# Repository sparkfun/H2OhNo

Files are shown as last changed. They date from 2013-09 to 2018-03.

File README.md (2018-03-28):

**Note:Retired Product**
This product has been retired from our catalog and is no longer for sale. This page is made available for those looking for datasheets and the simply curious.

H2OhNo
======

[H2OhNo 
*H20hNo (DEV-12069)*](https://www.sparkfun.com/products/12069)

H2OhNo! is a small ATtiny development board that detects the presence of water and sets off an alarm.

Repository Contents
-------------------

* **/Firmware** - Example firmware for running the sensor
* **/Hardware** - All Eagle design files (.brd, .sch)

Documentation
-------------------
* **[Hookup Guide](https://learn.sparkfun.com/tutorials/h2ohno)** - Basic hookup guide for the H2OhNo

License Information
-------------------
The hardware is released under [Creative Commons Share-alike 3.0](http://creativecommons.org/licenses/by-sa/3.0/).  
All other code is open source so please feel free to do anything you want with it; you buy me a beer if you use this and we meet someday ([Beerware license](http://en.wikipedia.org/wiki/Beerware)).

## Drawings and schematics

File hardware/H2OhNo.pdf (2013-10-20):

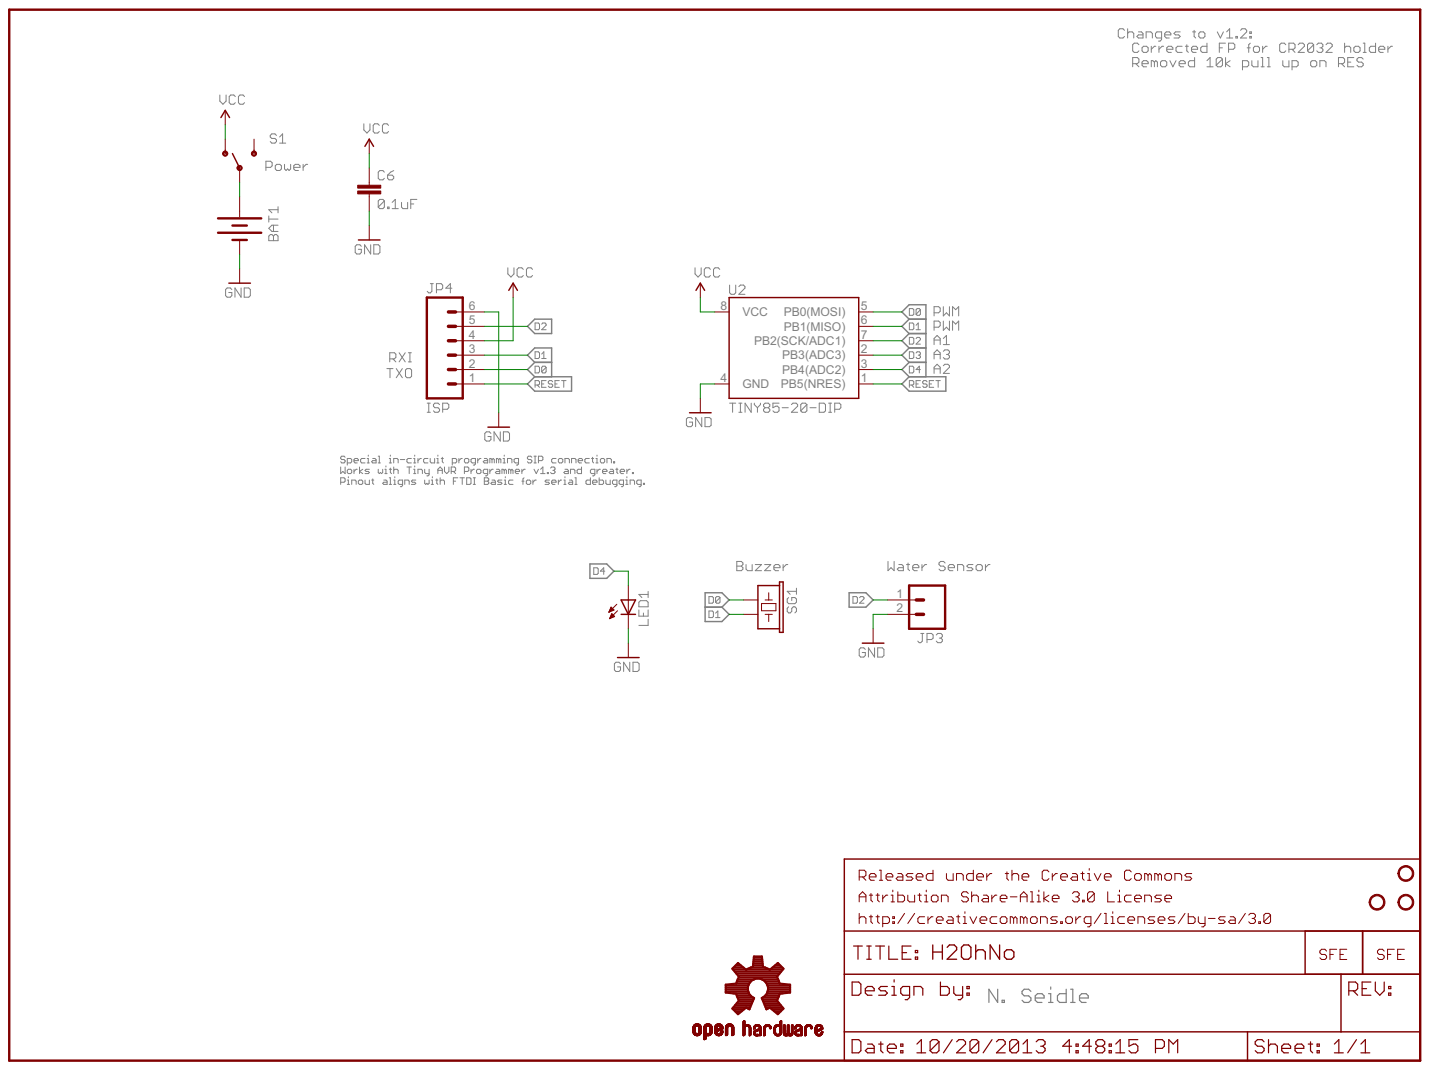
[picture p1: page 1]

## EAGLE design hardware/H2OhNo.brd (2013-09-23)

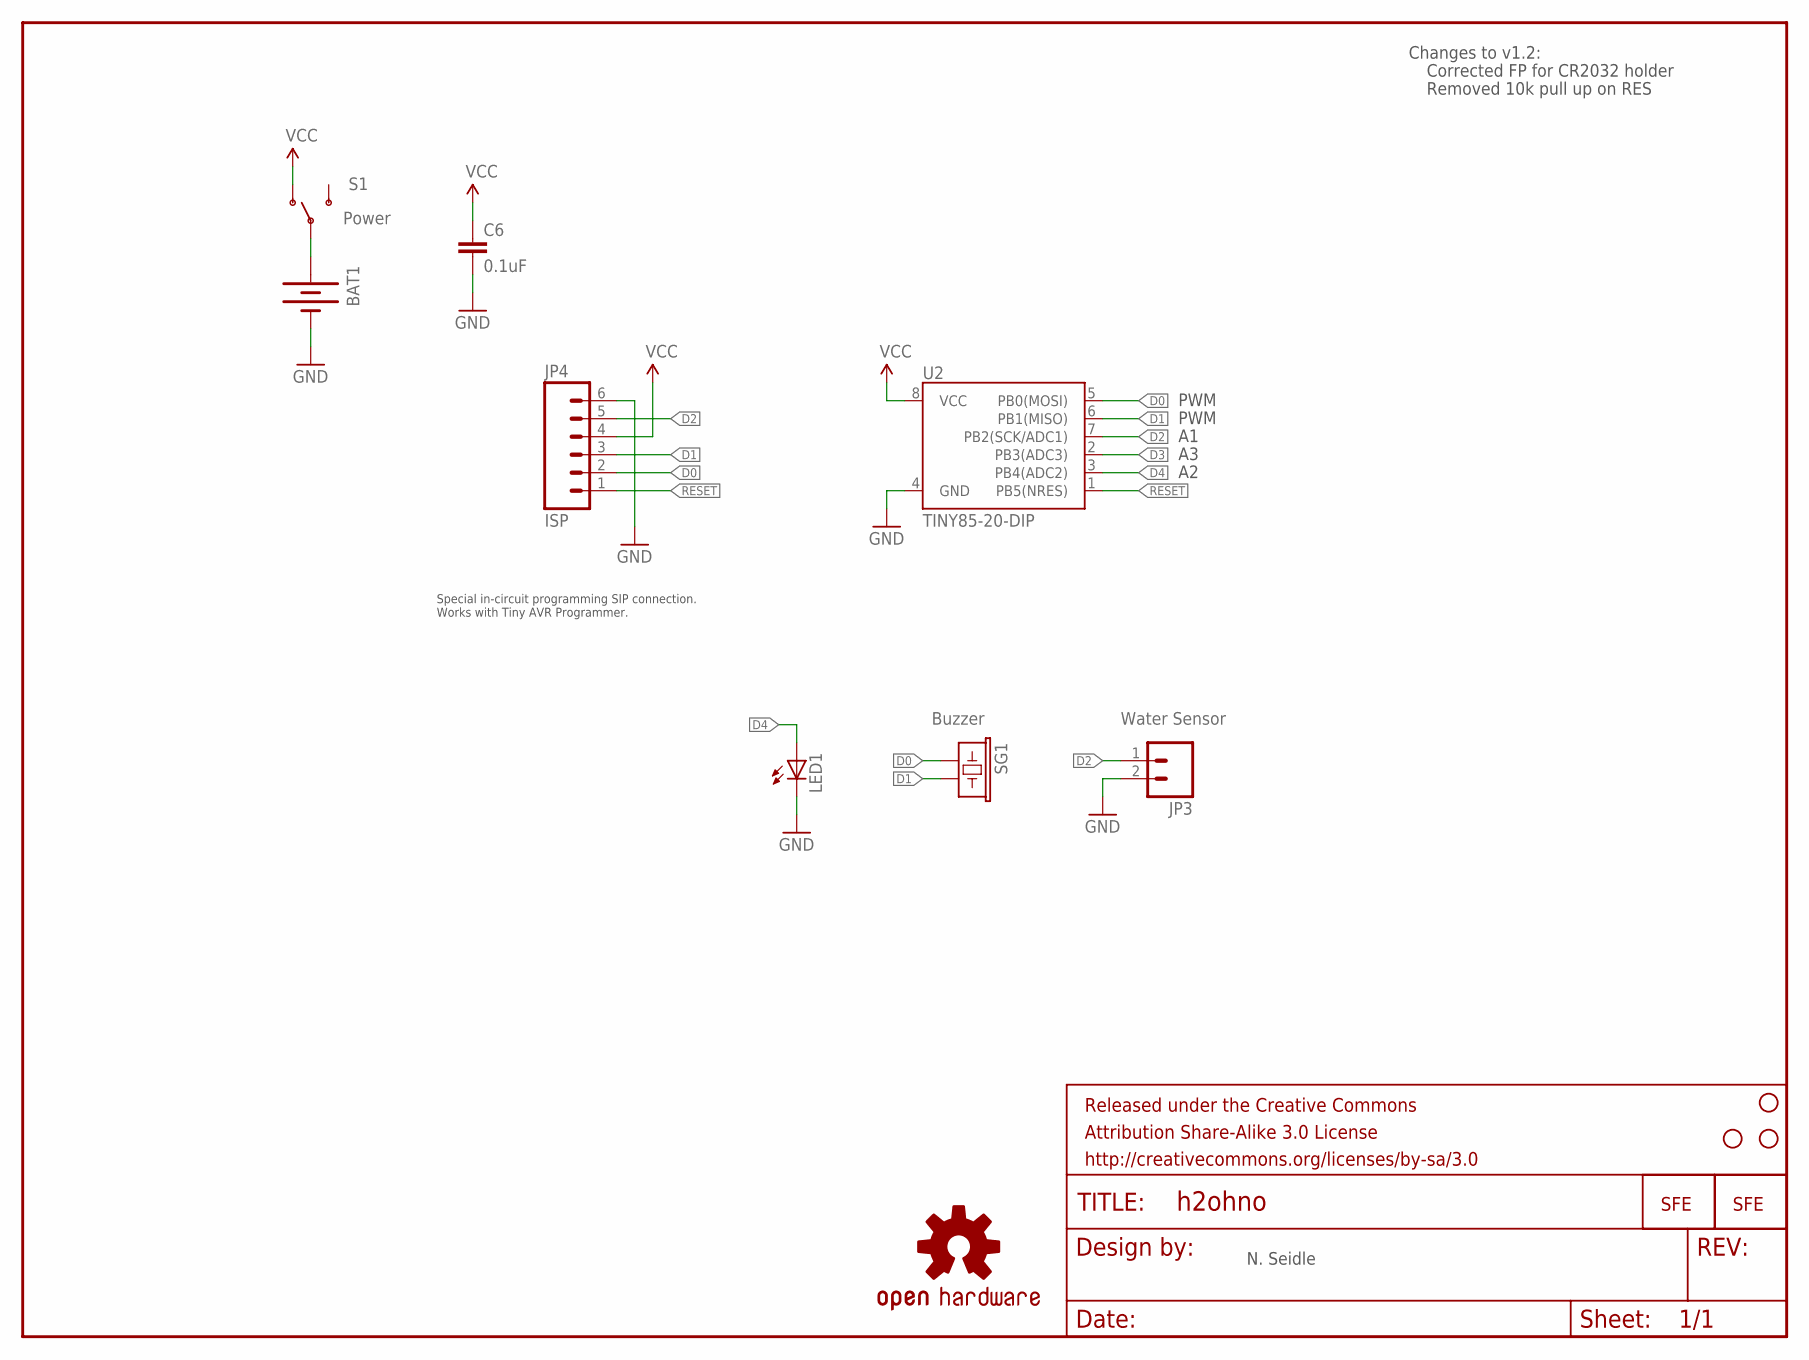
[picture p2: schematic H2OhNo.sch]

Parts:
BAT1: BATTERY20PTH; BATTCOM_20MM_PTH
C6: 0.1uF; CAP-PTH-SMALL2
FRAME2: FRAME-LETTER; CREATIVE_COMMONS
JP3: Water Sensor; 1X02
JP4: ISP; 1X06
LED1: LED5MM
S1: Power; SWITCH-SPDT
SG1: Buzzer; BUZZER-12MM
STANDOFF1, STANDOFF3, STANDOFF4: STAND-OFF
U2: TINY85-20-DIP; DIP08
U$1: LOGO-SFESK; SFE-LOGO-FLAME
U$4: OSHW-LOGOS; OSHW-LOGO-S
U$5: LOGO-SFENW2; SFE-NEW-WEB

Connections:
D0: JP4.2, SG1.+ (1), U2.5 (PB0(MOSI))
D1: JP4.3, SG1.- (2), U2.6 (PB1(MISO))
D2: JP3.1, JP4.5, U2.7 (PB2(SCK/ADC1))
D3: U2.2 (PB3(ADC3))
D4: LED1.A, U2.3 (PB4(ADC2))
GND: BAT1.2 (-), C6.2, JP3.2, JP4.6, LED1.K (C), U2.4 (GND)
unnamed: BAT1.1 (+), S1.2
RESET: JP4.1, U2.1 (PB5(NRES))
VCC: C6.1, JP4.4, S1.1 (O), U2.8 (VCC)

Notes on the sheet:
N. Seidle
Changes to v1.2:
PWM
Corrected FP for CR2032 holder
Removed 10k pull up on RES
Special in-circuit programming SIP connection. Works with Tiny AVR Programmer.

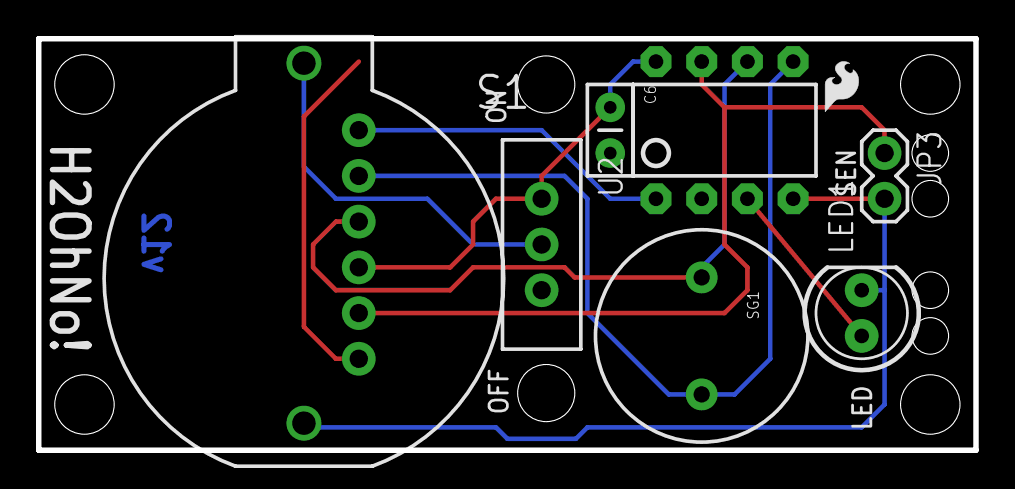
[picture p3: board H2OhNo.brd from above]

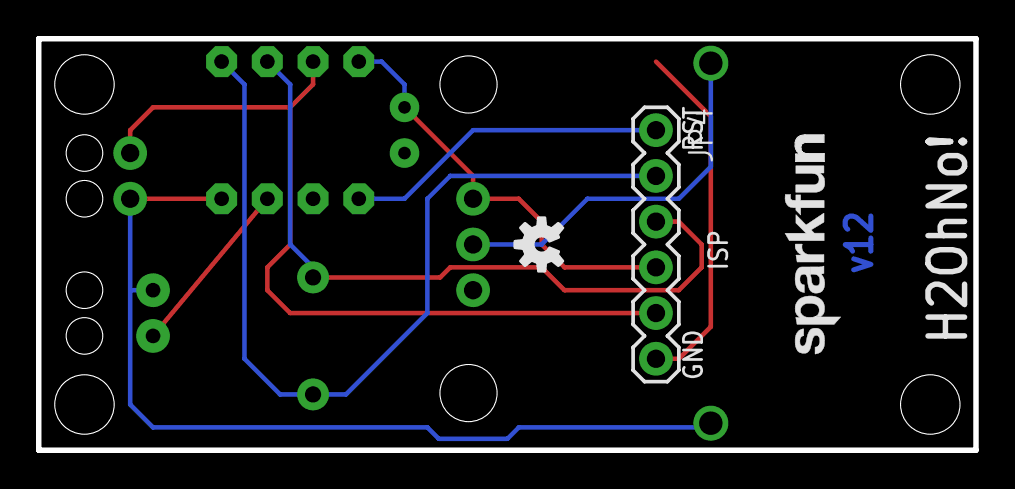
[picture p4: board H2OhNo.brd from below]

Board: 2 copper layers, 52.1 x 22.9 mm, 16 parts (3 on the bottom side), 8 nets.

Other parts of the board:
STANDOFF2: STAND-OFF

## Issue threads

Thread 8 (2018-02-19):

OHNO! Discontinued!

hevnsnt, 2018-02-19:
OH NO!

Any chance you all have a stack of these boards laying around and I could buy 10+ off of you?

bri-huang, 2018-02-20:
SparkFun provides the board files here. You can order these directly from OSHPark. If you haven't used their service, it's super easy and fast. For this size, it'll cost you just a bit more than $3 per board.

https://oshpark.com/shared_projects/DJ5Fg307

loricrotser, 2018-03-28:
@hevnsnt

Hi! I am closing this issue but please do let us know if you have any more questions!
Thank you!

Closed 2018-03-28.

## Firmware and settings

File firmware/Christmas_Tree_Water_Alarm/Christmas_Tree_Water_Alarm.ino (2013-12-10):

/*
 12-8-2013
 Spark Fun Electronics
 Nathan Seidle
 
 This code is public domain but you buy me a beer if you use this and we meet someday (Beerware license).
 
 When the ATtiny senses the lack of water between two pins, play jingle bells. Created to monitor the water level 
 of a Christmas Tree stand.  This is the reverse of the standard water alarm. We are going to set the alarm 
 off in the *absence* of water to let the user know to refill the Christmas tree. aka, H2OhYes!
 
 We take a series of readings of the water sensor at power up. We then wait for a deviation of more than
 100 from the average before triggering the alarm. The alarm will play every minute minute if water is not detected.
 
 This firmware uses some power saving to get the average consumption down to ~50uA average. With a CR2032 @ 200mAh 
 this should allow it to run for 4,000hrs or 166 days. This is easily extended by increasing the amount of time
 between water checks (currently once ever 4 seconds).
 
 */

#include <avr/sleep.h> //Needed for sleep_mode
#include <avr/wdt.h> //Needed to enable/disable watch dog timer

#include <SoftwareSerial.h>

SoftwareSerial mySerial(4, 3); // RX, TX

//Pin definitions for regular Arduino Uno (used during development)
/*const byte buzzer1 = 8;
 const byte buzzer2 = 9;
 const byte statLED = 10;
 const byte waterSensor = A0;*/

//Pin definitions for ATtiny
const byte buzzer1 = 0;
const byte buzzer2 = 1;
const byte statLED = 4;
const byte waterSensor = A1;

//Variables

//This is the average analog value found during startup. Usually ~995
//When hit with water, the analog value will drop to ~400. A diff of 100 is good.
int waterAvg = 0; 
int maxDifference = 100; //A diff of more than 100 in the analog value will trigger the system.
int wakeUpCounter = 0;

//This runs each time the watch dog wakes us up from sleep
ISR(WDT_vect) {
  //Don't do anything. This is just here so that we wake up.
}

void setup()
{
  pinMode(buzzer1, OUTPUT);
  pinMode(buzzer2, OUTPUT);
  pinMode(statLED, OUTPUT);

  //pinMode(waterSensor, INPUT_PULLUP);
  pinMode(2, INPUT); //When setting the pin mode we have to use 2 instead of A1
  digitalWrite(2, HIGH); //Hack for getting around INPUT_PULLUP

  mySerial.begin(9600);
  mySerial.println("Xmas tree monitor");

  //Take a series of readings from the water sensor and average them
  waterAvg = 0;
  for(int x = 0 ; x < 8 ; x++)
  {
    waterAvg += analogRead(waterSensor);

    //During power up, blink the LED to let the world know we're alive
    if(digitalRead(statLED) == LOW)
      digitalWrite(statLED, HIGH);
    else
      digitalWrite(statLED, LOW);

    delay(50);
  }
  waterAvg /= 8;

  mySerial.print("Avg: ");
  mySerial.println(waterAvg);

  digitalWrite(statLED, HIGH);
  playJingleBells();

  digitalWrite(buzzer1, LOW);
  digitalWrite(buzzer2, LOW);
  digitalWrite(statLED, LOW);

  //Power down various bits of hardware to lower power usage  
  set_sleep_mode(SLEEP_MODE_PWR_DOWN); //Power down everything, wake up from WDT
  sleep_enable();

}

void loop() 
{
  ADCSRA &= ~(1<<ADEN); //Disable ADC, saves ~230uA
  setup_watchdog(8); //Setup watchdog to go off after 4sec
  sleep_mode(); //Go to sleep! Wake up 1sec later and check water

  //Check for water
  ADCSRA |= (1<<ADEN); //Enable ADC
  int waterDifference = abs(analogRead(waterSensor) - waterAvg);
  mySerial.print("Diff: ");
  mySerial.println(waterDifference);

  if(waterDifference < maxDifference) //Ahhh! There's no water! Alarm!
  {
    wakeUpCounter++; 

    //We only want the alarm to go off every 60 seconds
    //The watchdog will wake us up every 4 seconds.
    //We use the wakeUpCounter to keep track of how many times we woke up
    //and detected a lack of water. If we have 60/4 = 15 consecutive wakeups with no
    //water then sound the alarm.

    if(wakeUpCounter > (60 / 4))
    {
      wdt_disable(); //Turn off the WDT

      wakeUpCounter = 0; //Reset the counter

      //Make a brief amount of noise. We don't want anyone going crazy.
      digitalWrite(statLED, HIGH);
      playJingleBells();

      digitalWrite(buzzer1, LOW);
      digitalWrite(buzzer2, LOW);
      digitalWrite(statLED, LOW); //No more alarm. Turn off LED
    }
  }
  else
    wakeUpCounter = 0; //Reset the counter
}

//Sets the watchdog timer to wake us up, but not reset
//0=16ms, 1=32ms, 2=64ms, 3=128ms, 4=250ms, 5=500ms
//6=1sec, 7=2sec, 8=4sec, 9=8sec
//From: http://interface.khm.de/index.php/lab/experiments/sleep_watchdog_battery/
void setup_watchdog(int timerPrescaler) {

  if (timerPrescaler > 9 ) timerPrescaler = 9; //Limit incoming amount to legal settings

  byte bb = timerPrescaler & 7; 
  if (timerPrescaler > 7) bb |= (1<<5); //Set the special 5th bit if necessary

  //This order of commands is important and cannot be combined
  MCUSR &= ~(1<<WDRF); //Clear the watch dog reset
  WDTCR |= (1<<WDCE) | (1<<WDE); //Set WD_change enable, set WD enable
  WDTCR = bb; //Set new watchdog timeout value
  WDTCR |= _BV(WDIE); //Set the interrupt enable, this will keep unit from resetting after each int

}

//From http://micahelsprofessionalportfolio.blogspot.com/2012/11/arduino-challenge-jingle-bells.html
//Note: On the ATtiny you have to pull arrays out of functions otherwise you get compile/pointer errors
char notes[] = "eeeeeeegcde"; // a space represents a rest
int beats[] = { 1, 1, 2, 1, 1, 2, 1, 1, 1, 1, 4};
void playJingleBells()
{
  int length = 11; // the number of notes
  int tempo = 100;

  for (char i = 0; i < length; i++)
  {
    if (notes[i] == ' ')
      delay(beats[i] * tempo); // rest
    else
      playNote(notes[i], beats[i] * tempo);

    // pause between notes
    delay(tempo / 2); 
  }

}

//Must be moved to global to compile on an ATtiny
char names[] = { 'c', 'd', 'e', 'f', 'g', 'a', 'b', 'C' };
int tones[] = { 1915, 1700, 1519, 1432, 1275, 1136, 1014, 956 };
void playNote(char note, int duration)
{
  // play the tone corresponding to the note name
  for (int i = 0; i < 8; i++) {
    if (names[i] == note) {
      playTone(tones[i], duration);
    }
  }
}

void playTone(int frequency, int duration)
{
  for (long i = 0 ; i < duration * 1000L ; i += frequency * 2)
  {
    digitalWrite(buzzer2, HIGH);
    digitalWrite(buzzer1, LOW);
    delayMicroseconds(frequency);
    digitalWrite(buzzer2, LOW);
    digitalWrite(buzzer1, HIGH);
    delayMicroseconds(frequency);
  }
}

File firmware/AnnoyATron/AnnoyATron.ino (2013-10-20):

/*
 1-14-2013
 Spark Fun Electronics
 Nathan Seidle
 
 This code is public domain but you buy me a beer if you use this and we meet someday (Beerware license).
 
 Annoy-A-Tron is a super scary product that Think Geek sells: http://www.thinkgeek.com/product/b278/
 
 This is a very basic Annoy-A-Tron example that will beep every 5 minutes. We intentionally didn't build in
 low-power control so that if you happen to use this code you will only annoy your enemy for a few hours
 before the coin cell battery gives out.
 
 */

//Pin definitions for ATtiny
const byte buzzer1 = 0;
const byte buzzer2 = 1;

void setup()
{
  pinMode(buzzer1, OUTPUT);
  pinMode(buzzer2, OUTPUT);
}

void loop() 
{
  alarmSound();
  
  delay((long)1000 * 60 * 5); //5 minute delay
}

//This is just a unique (annoying) sound we came up with, there is no magic to it
//Comes from the Simon Says game/kit actually: https://www.sparkfun.com/products/10547
//250us to 79us
void alarmSound(void)
{
  // Toggle the buzzer at various speeds
  for (byte x = 250 ; x > 70 ; x--) 
  {
    //for (byte y = 0 ; y < 3 ; y++)
    for (byte y = 0 ; y < 1 ; y++) //Slightly modified to be a shorter beep
    {
      digitalWrite(buzzer2, HIGH);
      digitalWrite(buzzer1, LOW);
      delayMicroseconds(x);

      digitalWrite(buzzer2, LOW);
      digitalWrite(buzzer1, HIGH);
      delayMicroseconds(x);
    }
  }
}

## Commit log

2013-04-03 Pushing version 1 of the files.
    This version works. Need to increase isolation to 0.012.
    [H2OhNo-v10.brd, H2OhNo-v10.sch]
2013-09-23 Added version #. Fixed file naming. Removed 10k on RES.
    Fixed footprint on CR2032 as well.
    [H2OhNo-v10.brd, H2OhNo-v10.sch, H2OhNo.brd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]
2013-09-23 Remove legacy code. Works under Arduino v1.0.5.
2013-09-23 Modified 6-pin SIP header for FTDI compatibility
    It's not serial, but you should be able to bit-bang serial out the
    MOSI/MISO lines and use an FTDI on the programming header. Good for
    debugging.
    [H2OhNo.brd, H2OhNo.sch]
2013-09-23 Hardware changes to address issues on github.
    Moved 0.1uF cap closer to IC. Added standoffs. Increased board size.
    Moved LED and sense towards end of board.
    [H2OhNo.brd, H2OhNo.sch]
2013-10-14 Added power saving to main firmware. Should run for 150+ days.
    Got current usage down to ~50uA. Should run for 166 days on a CR2032.
2013-10-20 Creating and updating example code for tutorial hook up guide.
    [H2OhNo.sch]
2013-11-15 Adding version number to schematic
    [H2OhNo.sch]
2013-12-10 Adding status LED to Xmas example

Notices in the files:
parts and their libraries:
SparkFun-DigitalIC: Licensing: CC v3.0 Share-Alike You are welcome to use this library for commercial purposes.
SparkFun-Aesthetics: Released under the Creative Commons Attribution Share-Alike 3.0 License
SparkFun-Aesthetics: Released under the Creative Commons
